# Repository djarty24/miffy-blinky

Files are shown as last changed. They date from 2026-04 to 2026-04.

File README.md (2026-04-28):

# miffy-blinky! 🐰✨

This is my first PCB project. I made a custom Miffy-shaped blinky keychain following Hack Club's Stasis project started guide! 

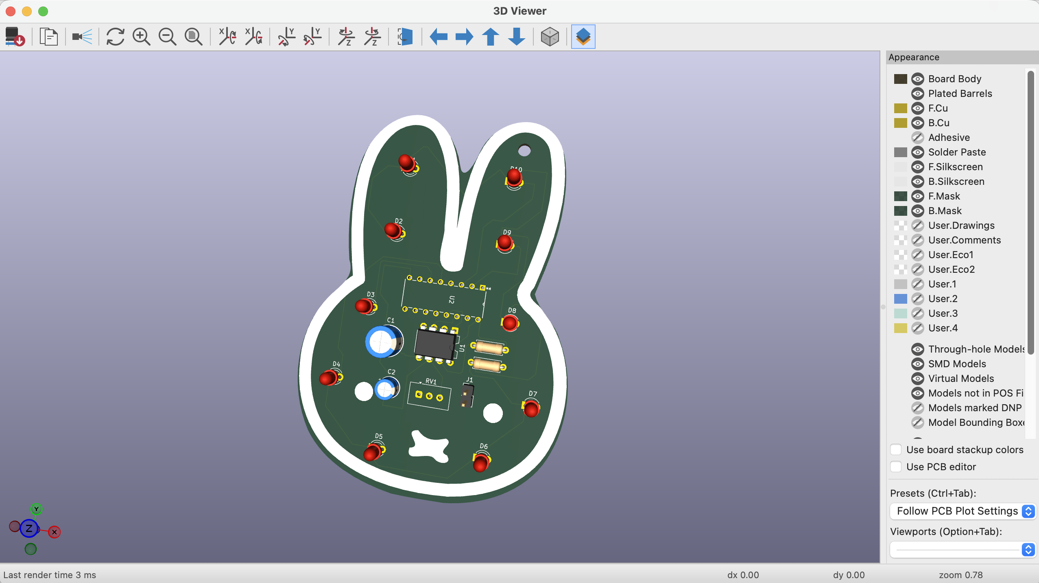
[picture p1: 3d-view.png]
Miffy 3D Render


Coming from mostly web dev and frontend stuff, jumping into KiCad was definitely an experience. It turns out making a PCB is basically like doing UI design, except the components actually take up physical space and you can't just z index them away lol. 

### What I learned
* I learned how to physically route components on the PCB.
* I imported a custom DXF drawing for Miffy's face, but it wouldn't show up in the 3D viewer. Turns out CAD lines have a 0mm thickness by default, so I had to manually set the ink to 0.2mm so the factory actually prints it!
* Drawing the copper tracks is honestly like a puzzle game. You can't cross a front wire over another front wire without shorting the board, but you can drop a pin and draw on the back layer to go underneath. 

Super proud of how this turned out!

## Journal

I finally finished my first ever custom hardware project! I made a PCB shaped like Miffy, one of my favorite characters, that also doubles as a keychain.

## Schematic
The first step is in the schematic editor of KiCad to design the circuit. Here, I placed symbols for the 555 timer, a 4017 counter, a power bank, two capacitors, two resistors, and 10 LEDs.

In my Principles of Engineering class in school, we briefly covered circuitry, but I was under the assumption that everything needs to be connected. However, something cool I learned was using labels. This kept my schematic design cleaner and more readable.



## Footprints
I followed the guide to add the custom 4017 counter footprint to my project. Then, I switched to the PCB view, only to find that I couldn't actually move the LEDs. After a lot of troubleshooting, I realized that I hadn't added any footprints for the rest of my components like the actual LEDs.

## PCB Design
This was the most fun part!

### Positioning
Now that the footprints were installed, I uploaded a DXF file of Miffy. I learned about grouping and ungrouping and how to set each part of her face on the correct layer. I changed the border to be an Edge Cut for the outline of the PCB. Then, I placed the components and LEDs where I wanted on the board.

### Copper Wiring
Now that everything was positioned where I wanted it to be, I had to replace the ratsnets with copper tracks. This was both therapeutic and frustrating at times because you can't have two lines of the same color cross. When a red track blocked my path, I switched to the blue layer and vice versa.



The Design Rules Checker tool was extremely helpful because it helped me catch mistakes I made.

Finally, I added another hole from the Edge Cuts layer with a diameter of 1.5 mm to serve as the hole where I can insert my keychain later. I also converted Miffy's eyes and mouth into Polygons (this took a lot longer than expected) and filled them in.

## Gerbers
This was the last step, I just generated the gerber and drill files and saved them into a zip. Then, I went to JLCPCB to get a price estimate. I changed the color of my PCB to white, and so the drawings turned black, so it actually looks pretty similar to the original Miffy character!



I also pushed my files to GitHub and wrote up a quick README for my project.

## Final Thoughts
This was my first time working with PCBs and it was an awesome experience. Designing a physical object that I can hold in my hands is completely different from anything I've done before since I usually just write software. I learned a lot about designing readable schematics and positioning them on the actual PCB.

Even though there was a huge learning curve and a fair share of frustrating moments, I learned a lot and it was really fun!

I had so much fun building this Miffy blinky keychain and I'm definitely going to design more PCBs in the future!

---
<div align="center">

### This project was made for Hack Club's Stasis event.
</div>

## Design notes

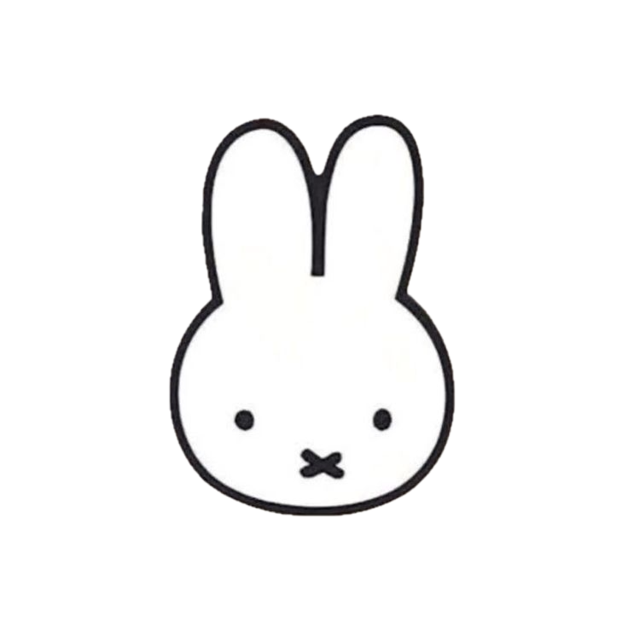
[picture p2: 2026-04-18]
miffy.png

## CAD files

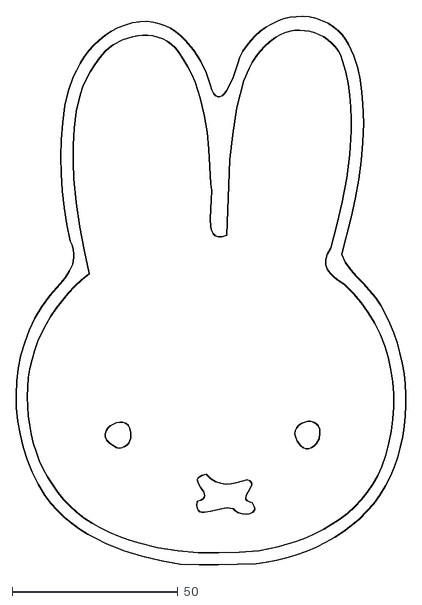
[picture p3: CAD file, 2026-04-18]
miffy.dxf
117.4 x 165.2

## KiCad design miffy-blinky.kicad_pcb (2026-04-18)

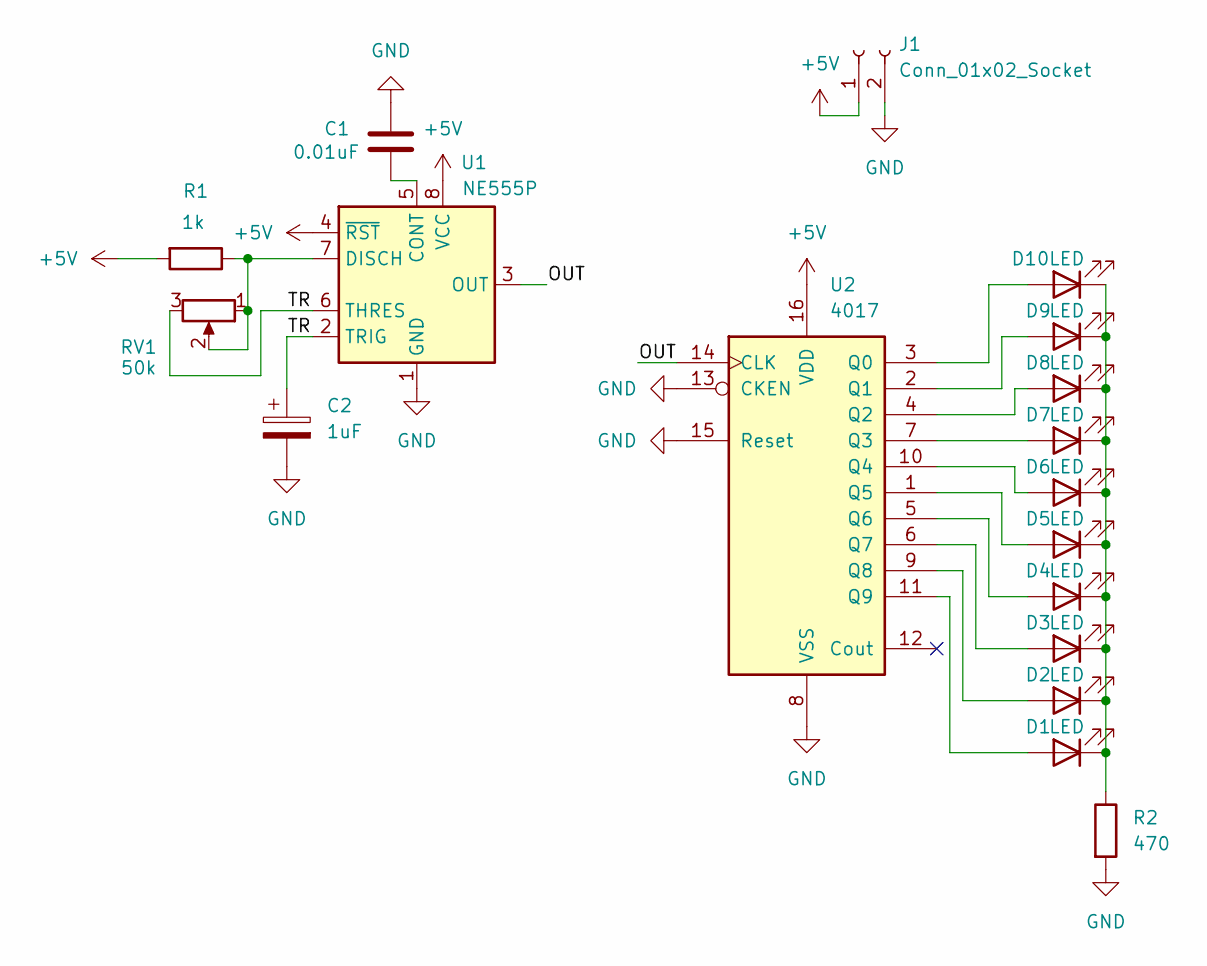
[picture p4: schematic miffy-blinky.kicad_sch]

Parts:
C1: 0.01uF
C2: 1uF
D1, D2, D3, D4, D5, D6, D7, D8, D9, D10: LED
J1: Conn_01x02_Socket
R1: 1k
R2: 470
RV1: 50k
U1: NE555P; DIP-8_W7.62mm
U2: 4017; N16

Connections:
+5V: J1.1, R1.2, U1.4 (~RST), U1.8 (VCC), U2.16 (VDD)
/OUT: U1.3 (OUT), U2.14 (CLK)
/TR: C2.1, RV1.3, U1.2 (TRIG), U1.6 (THRES)
GND: C1.1, C2.2, J1.2, R2.2, U1.1 (GND), U2.8 (VSS), U2.13 (CKEN), U2.15 (Reset)
unnamed: D1.2 (A), U2.11 (Q9)
unnamed: D1.1 (K), D2.1 (K), D3.1 (K), D4.1 (K), D5.1 (K), D6.1 (K), D7.1 (K), D8.1 (K), D9.1 (K), D10.1 (K), R2.1
unnamed: D2.2 (A), U2.9 (Q8)
unnamed: D3.2 (A), U2.6 (Q7)
unnamed: D4.2 (A), U2.5 (Q6)
unnamed: D5.2 (A), U2.1 (Q5)
unnamed: D6.2 (A), U2.10 (Q4)
unnamed: D7.2 (A), U2.7 (Q3)
unnamed: D8.2 (A), U2.4 (Q2)
unnamed: D9.2 (A), U2.2 (Q1)
unnamed: D10.2 (A), U2.3 (Q0)
unnamed: C1.2, U1.5 (CONT)
unnamed: R1.1, RV1.1, RV1.2, U1.7 (DISCH)

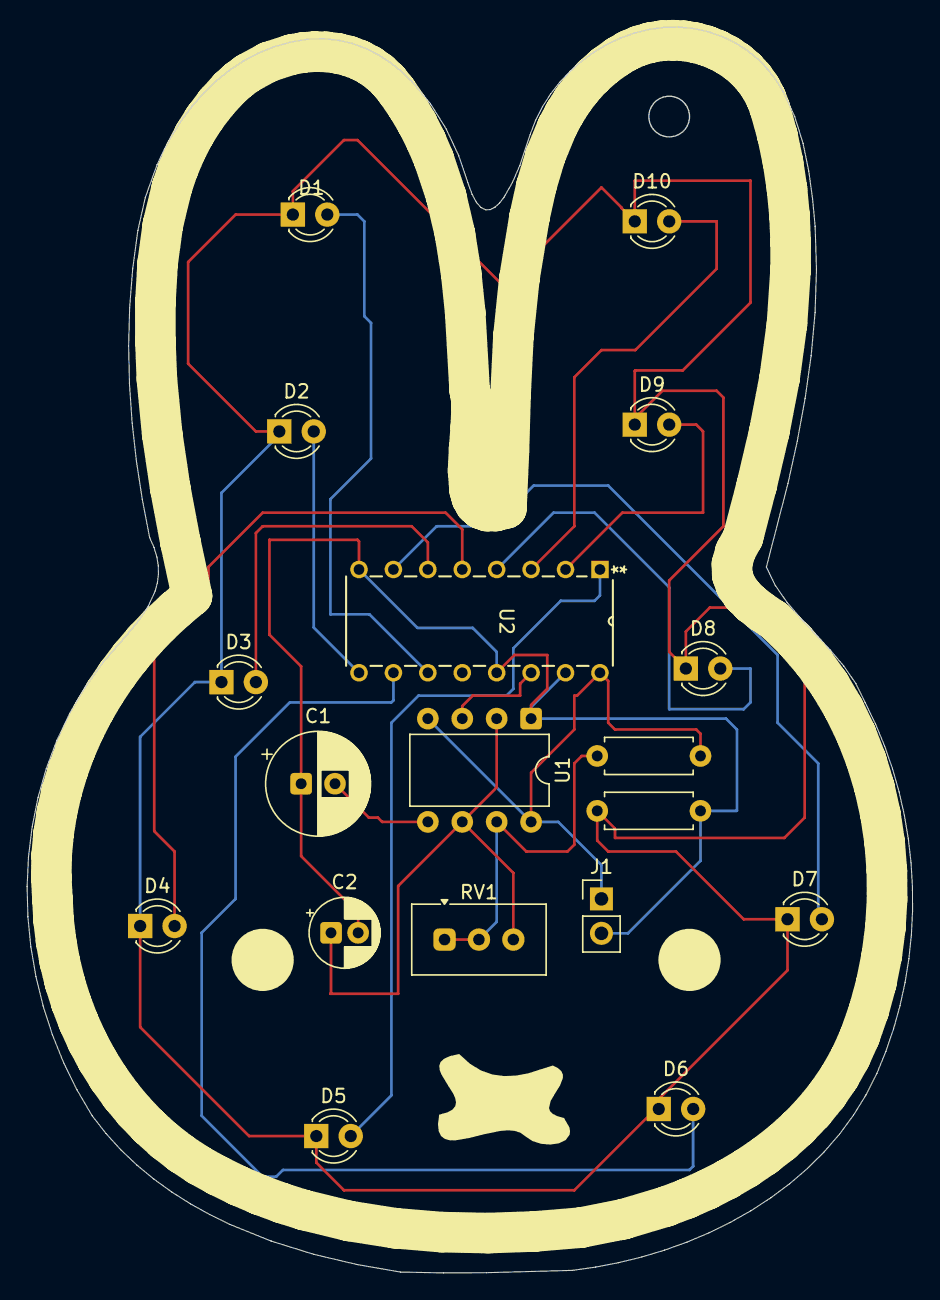
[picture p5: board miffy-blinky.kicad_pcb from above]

Board: 2 copper layers, 65.3 x 91.9 mm, 18 parts (0 on the bottom side), 17 nets.

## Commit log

2026-04-18 finished miffy pcb design from starter project tutorial
    [miffy-blinky-B_Cu.gbr, miffy-blinky-B_Mask.gbr, miffy-blinky-B_Paste.gbr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]
2026-04-18 added keychain hole and updated gerbers
    [miffy-blinky-B_Cu.gbr, miffy-blinky-B_Mask.gbr, miffy-blinky-B_Paste.gbr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]
2026-04-28 Enhance README with project details and insights
    Added detailed project journal, schematic, footprints, PCB design, Gerbers, and final thoughts sections to README.
